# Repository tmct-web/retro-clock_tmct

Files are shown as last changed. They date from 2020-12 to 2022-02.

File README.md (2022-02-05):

# retro-clock_tmct
All discrete logic clock

Retro-clock picture

This is a clock made by combining only logic ICs, so-called DIP components, without using a microcontroller.  
KiCad project files are available.

You can find more information on the following page. (*Japanese only)

[tmct web-site:nixie-clock](https://ss1.xrea.com/tmct.s1009.xrea.com/work/td-ja-7e4l01.html)

---
マイコンを使わず、いわゆるDIP部品のロジックICだけを組み合わせて作った時計です。  
KiCadのプロジェクトファイル一式を公開しています。

設計の仕様・組み立て方などの詳細は下記のページをご覧ください。

[tmct web-site:nixie-clock](https://ss1.xrea.com/tmct.s1009.xrea.com/work/td-ja-7e4l01.html)

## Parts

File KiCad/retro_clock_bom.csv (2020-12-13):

Reference | Quantity | Value | Remarks
C1 | 1 | 1500u/25V | ???????
C11;C12;C14;C13;C8;C17;C18;C2;C16;C9;C15;C10;C19;C20;C21;C22;C28;C24;C26;C29;C27;C25;C23;C34;C35;C41;C40;C42;C39;C38;C44;C43;C60;C61;C62;C55;C49;C63;C46;C64;C54;C48;C47;C52;C59;C65;C58;C57;C71;C72;C77;C82;C78;C83;C79;C84;C80;C85;C81;C86;C73;C74;C75;C76 | 64 | 0.1u/50V | ??????????
C3;C4 | 2 | 10u/400V | ???????
C5;C7;C87;C88;C30;C32;C31;C33;C36;C37;C45;C50;C53;C56;C51;C66;C67;C68;C69;C70 | 20 | 1u/50V | ??????????
C6 | 1 | 100u/16V | ???????
C94;C95;C96;C97;C98;C99;C100 | 7 | 10u/25V | ??????????
CDS1 | 1 | GL5528
CN1 | 1 | B3P-VH(LF)(SN) | JST
CN3 | 1 | XH_B8B-XH-A | JST
CN4;CN2 | 2 | XH_B4B-XH-A | JST
D1 | 1 | S1ZB
D10 | 1 | LED
D4;D5;D7;D8 | 4 | UF2010
D6 | 1 | GDZJ4.7C
D9;D3;D11;D2 | 4 | BAT43
IC1;IC4;IC6 | 3 | 74HC14
IC13;IC27;IC29;IC28;IC45;IC53;IC54;IC55 | 8 | 74HC04
IC15;IC12;IC11;IC38;IC35;IC34 | 6 | 74HC32
IC16 | 1 | 74HC283
IC17;IC14;IC33;IC31;IC30;IC43;IC44;IC46 | 8 | 74HC08
IC2 | 1 | LM2940T-5.0
IC20;IC21;IC22;IC23;IC18;IC19 | 6 | 74HC157
IC25;IC26;IC24;IC39 | 4 | 74HC273
IC3 | 1 | NJU7043
IC32 | 1 | 74HC541
IC36;IC42;IC37;IC56;IC57;IC58 | 6 | 74HC21
IC40;IC41;IC47;IC48;IC49;IC50;IC51;IC52 | 8 | 74HC161
IC5 | 1 | LM393
IC7;IC8;IC9;IC10 | 4 | K155ID1
NE1;NE2;NE3 | 3 | Lamp_Neon | ????
NX1;NX2;NX3;NX4 | 4 | IN-12A | ?????(????????)
PC1 | 1 | TLP222G-2
Q1;Q2 | 2 | MPSA42
R11 | 1 | 2.7k/5%
R13;R12;R7;R15;R35;R38 | 6 | 100k/5%
R14;R3;R22;R21;R20;R23;R24;R5 | 8 | 4.7k/5%
R17;R16;R1;R36;R39 | 5 | 10k/5%
R18;R19 | 2 | 330/5%
R2 | 1 | 8.2k/5%
R25;R26;R27;R28;R10;R9;R29 | 7 | 1k/5%
R30 | 1 | 0
R31;R32;R33;R34;R53;R54;R55;R52 | 8 | 20k/5%/0.5W
R37;R40;R41 | 3 | 200k/5%/0.5W
R4 | 1 | 6.8k/5%
R44;R45;R46;R47;R48;R49;R50;R51;R42;R43 | 10 | 33/5%
R56;R57;R58 | 3 | 33k/5%/0.5W
R6 | 1 | 3.3k/5%
R8 | 1 | 1M/5%/0.5W
RV2;RV1 | 2 | Bourns_3296W/10k | ????????
SW1;SW3;SW4 | 3 | TVDT18-050CB-T | ???????????
SW2;SW5 | 2 | IS-2235-G | ????????????
T1 | 1 | HP-612 | ????????
 |  | HT-1205 | ??????
C89;C90;C93;C91;C92 | 5 | UnPop | ???

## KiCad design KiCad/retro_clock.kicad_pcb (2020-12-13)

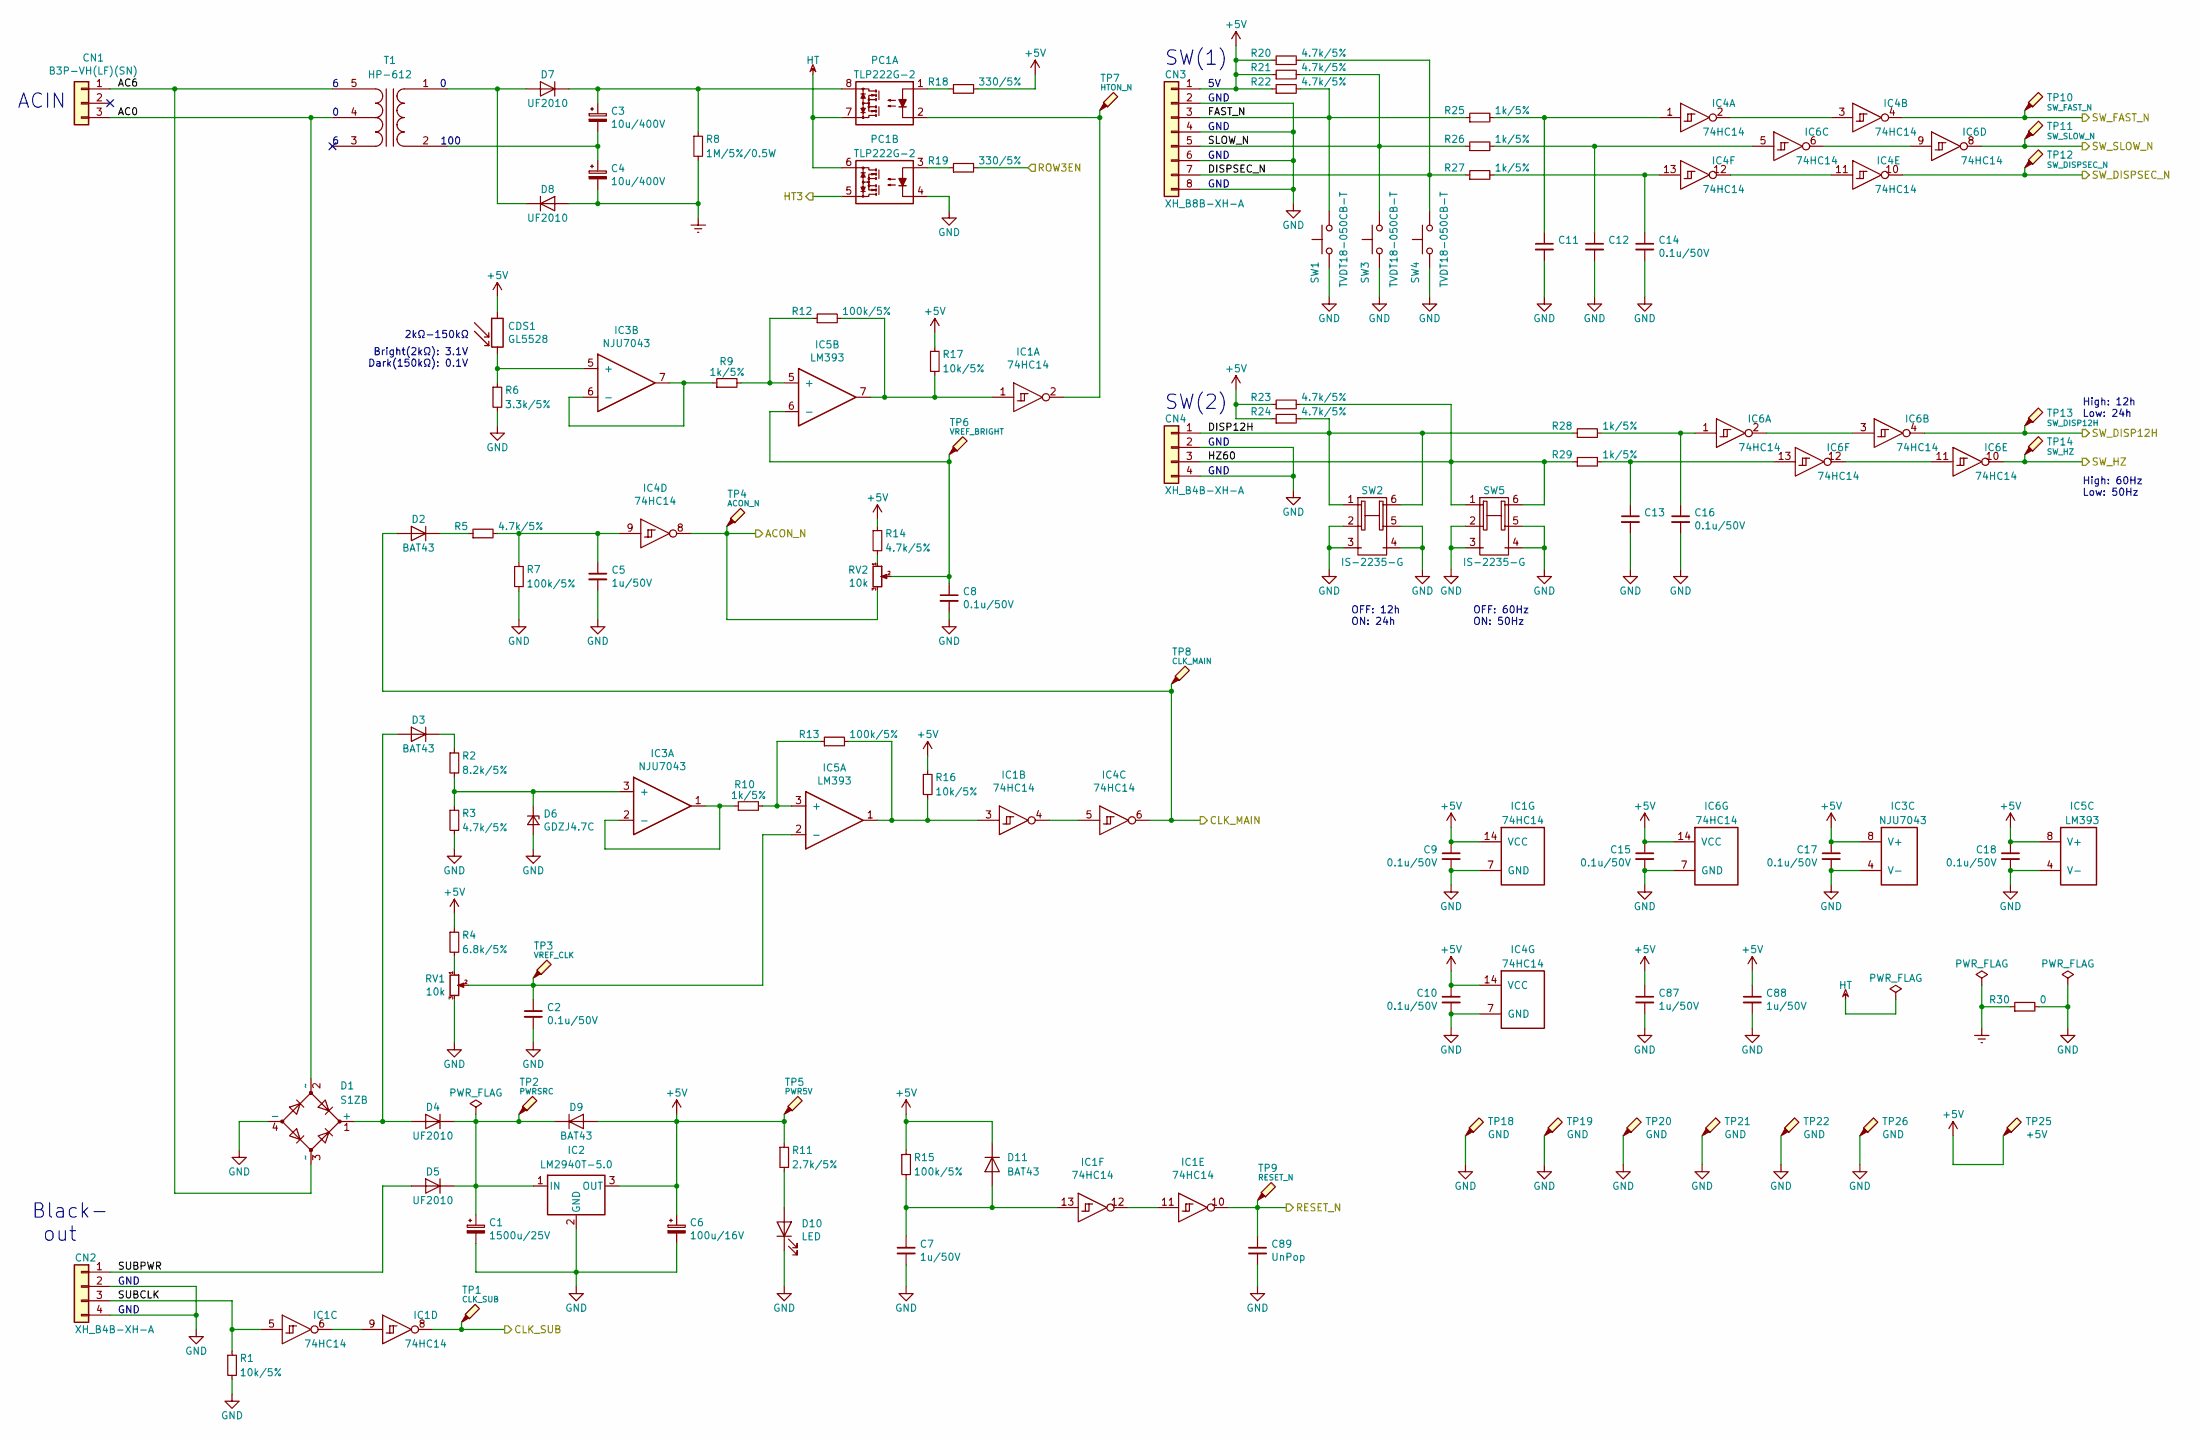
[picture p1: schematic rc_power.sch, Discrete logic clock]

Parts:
C1: 1500u/25V; CP_Radial_D12.5mm_P5.00mm
C2, C8, C9, C10, C11, C12, C13, C14, C15, C16, C17, C18: 0.1u/50V; C_Disc_P2.50mm
C3, C4: 10u/400V; CP_Radial_D12.5mm_P5.00mm
C5, C7, C87, C88: 1u/50V; C_Disc_P2.50mm
C6: 100u/16V; CP_Radial_D5.0mm_P2.00mm
C89: UnPop; C_Disc_P2.50mm
CDS1: GL5528; R_CDS_5.1x4.3mm_P3.4mm_Vertical
CN1: B3P-VH(LF)(SN); JST_VH_B3P-VH-B_1x03_P3.96mm_Vertical
CN2, CN4: XH_B4B-XH-A; JST_XH_B4B-XH-A_1x04_P2.50mm_Vertical
CN3: XH_B8B-XH-A; JST_XH_B8B-XH-A_1x08_P2.50mm_Vertical
D1: S1ZB; S1ZB-THD
D2, D3, D9, D11: BAT43; D_A-405_P7.62mm_Horizontal
D4, D5, D7, D8: UF2010; D_A-405_P10.16mm_Horizontal
D6: GDZJ4.7C; D_A-405_P7.62mm_Horizontal
D10: LED; LED_D3.0mm
IC1, IC4, IC6: 74HC14; DIP-14_W7.62mm_Socket_LongPads
IC2: LM2940T-5.0; TO-220-3_Vertical
IC3: NJU7043; DIP-8_W7.62mm_Socket_LongPads
IC5: LM393; DIP-8_W7.62mm_Socket_LongPads
PC1: TLP222G-2; DIP-8_W7.62mm_Socket_LongPads
R1, R16, R17: 10k/5%; R_Axial_P5.08mm_Horizontal
R2: 8.2k/5%; R_Axial_P5.08mm_Horizontal
R3, R5, R14, R20, R21, R22, R23, R24: 4.7k/5%; R_Axial_P5.08mm_Horizontal
R4: 6.8k/5%; R_Axial_P5.08mm_Horizontal
R6: 3.3k/5%; R_Axial_P5.08mm_Horizontal
R7, R12, R13, R15: 100k/5%; R_Axial_P5.08mm_Horizontal
R8: 1M/5%/0.5W; R_Axial_P7.62mm_Horizontal
R9, R10, R25, R26, R27, R28, R29: 1k/5%; R_Axial_P5.08mm_Horizontal
R11: 2.7k/5%; R_Axial_P5.08mm_Horizontal
R18, R19: 330/5%; R_Axial_P5.08mm_Horizontal
R30: 0; R_Axial_P5.08mm_Horizontal
RV1, RV2: 10k; Potentiometer_Bourns_3296W_Vertical
SW1, SW3, SW4: TVDT18-050CB-T
SW2, SW5: IS-2235-G
T1: HP-612; HP-098
TP1: CLK_SUB; TestPoint_THTPad_1.5x1.5mm_Drill0.7mm
TP2: PWRSRC; TestPoint_THTPad_1.5x1.5mm_Drill0.7mm
TP3: VREF_CLK; TestPoint_THTPad_1.5x1.5mm_Drill0.7mm
TP4: ACON_N; TestPoint_THTPad_1.5x1.5mm_Drill0.7mm
TP5: PWR5V; TestPoint_THTPad_1.5x1.5mm_Drill0.7mm
TP6: VREF_BRIGHT; TestPoint_THTPad_1.5x1.5mm_Drill0.7mm
TP7: HTON_N; TestPoint_THTPad_1.5x1.5mm_Drill0.7mm
TP8: CLK_MAIN; TestPoint_THTPad_1.5x1.5mm_Drill0.7mm
TP9: RESET_N; TestPoint_THTPad_1.5x1.5mm_Drill0.7mm
TP10: SW_FAST_N; TestPoint_THTPad_1.5x1.5mm_Drill0.7mm
TP11: SW_SLOW_N; TestPoint_THTPad_1.5x1.5mm_Drill0.7mm
TP12: SW_DISPSEC_N; TestPoint_THTPad_1.5x1.5mm_Drill0.7mm
TP13: SW_DISP12H; TestPoint_THTPad_1.5x1.5mm_Drill0.7mm
TP14: SW_HZ; TestPoint_THTPad_1.5x1.5mm_Drill0.7mm
TP18, TP19, TP20, TP21, TP22, TP26: GND; TestPoint_Loop_D2.60mm_Drill0.9mm_Beaded
TP25: +5V; TestPoint_Loop_D2.60mm_Drill0.9mm_Beaded

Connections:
+5V: C6.1, C9.1, C10.1, C15.1, C17.1, C18.1, C87.1, C88.1, CDS1.1, CN3.1, D9.2 (A), D11.1 (K), IC1.14 (VCC), IC2.3 (OUT), IC3.8 (V+), IC4.14 (VCC), IC5.8 (V+), IC6.14 (VCC), R4.1, R11.1, R14.1, R15.1, R16.1, R17.1, R18.2, R20.1, R21.1, R22.1, R23.1, R24.1, TP5.1, TP25.1; also elsewhere on the board
/Display block/HT3: PC1.5; also elsewhere on the board
/Divider block/ACON_N: IC4.8, RV2.3, TP4.1; also elsewhere on the board
/Divider block/CLK_MAIN: D2.2 (A), IC4.6, TP8.1; also elsewhere on the board
/Divider block/CLK_SUB: IC1.8, TP1.1; also elsewhere on the board
/Divider block/RESET_N: C89.1, IC1.10, TP9.1; also elsewhere on the board
/Divider block/SW_DISP12H: IC6.4, TP13.1; also elsewhere on the board
/Divider block/SW_DISPSEC_N: IC4.10, TP12.1; also elsewhere on the board
/Divider block/SW_FAST_N: IC4.4, TP10.1; also elsewhere on the board
/Divider block/SW_HZ: IC6.10, TP14.1; also elsewhere on the board
/Divider block/SW_SLOW_N: IC6.8, TP11.1; also elsewhere on the board
/Driver block/ROW3EN: R19.2; also elsewhere on the board
/Power block/AC0: CN1.3, D1.2 (~~), T1.4 (SC)
/Power block/AC6: CN1.1, D1.3 (~~), T1.5 (SB)
/Power block/DISP12H: CN4.1, R24.2, R28.1, SW2.1 (1a), SW2.6 (2a)
/Power block/DISPSEC_N: CN3.7, R20.2, R27.1, SW4.2
/Power block/FAST_N: CN3.3, R22.2, R25.1, SW1.2
/Power block/HZ60: CN4.3, R23.2, R29.1, SW5.1 (1a), SW5.6 (2a)
/Power block/SLOW_N: CN3.5, R21.2, R26.1, SW3.2
/Power block/SUBCLK: CN2.3, IC1.5, R1.1
/Power block/SUBPWR: CN2.1, D5.2 (A)
Earth: C4.2, D8.2 (A), R8.2, R30.1; also elsewhere on the board
GND: C1.2, C2.2, C5.2, C6.2, C7.2, C8.2, C9.2, C10.2, C11.2, C12.2, C13.2, C14.2, C15.2, C16.2, C17.2, C18.2, C87.2, C88.2, C89.2, CN2.2, CN2.4, CN3.2, CN3.4, CN3.6, CN3.8, CN4.2, CN4.4, D1.4 (-), D6.2 (A), D10.1 (K), IC1.7 (GND), IC2.2 (GND), IC3.4 (V-), IC4.7 (GND), IC5.4 (V-), IC6.7 (GND), PC1.4, R1.2, R3.2, R6.2, R7.2, R30.2, RV1.3, SW1.1, SW2.2 (1c), SW2.3 (1b), SW2.4 (2b), SW2.5 (2c), SW3.1, SW4.1, SW5.2 (1c), SW5.3 (1b), SW5.4 (2b), SW5.5 (2c), TP18.1, TP19.1, TP20.1, TP21.1, TP22.1, TP26.1; also elsewhere on the board
HT: PC1.6, PC1.7; also elsewhere on the board
unnamed: C1.1, D4.1 (K), D5.1 (K), D9.1 (K), IC2.1 (IN), TP2.1
unnamed: C2.1, IC5.2 (-), RV1.2, TP3.1
unnamed: C3.1, D7.1 (K), PC1.8, R8.1
unnamed: C3.2, C4.1, T1.2 (AB)
unnamed: C5.1, IC4.9, R5.2, R7.1
unnamed: C7.1, D11.2 (A), IC1.13, R15.2
unnamed: C8.1, IC5.6 (-), RV2.2, TP6.1
unnamed: C11.1, IC4.1, R25.2
unnamed: C12.1, IC6.5, R26.2
unnamed: C13.1, IC6.13, R29.2
unnamed: C14.1, IC4.13, R27.2
unnamed: C16.1, IC6.1, R28.2
unnamed: CDS1.2, IC3.5 (+), R6.1
unnamed: D1.1 (+), D3.2 (A), D4.2 (A)
unnamed: D2.1 (K), R5.1
unnamed: D3.1 (K), R2.1
unnamed: D6.1 (K), IC3.3 (+), R2.2, R3.1
unnamed: D7.2 (A), D8.1 (K), T1.1 (AA)
unnamed: D10.2 (A), R11.2
unnamed: IC1.1, IC5.7, R12.2, R17.2
unnamed: IC1.2, PC1.2, TP7.1
unnamed: IC1.3, IC5.1, R13.2, R16.2
unnamed: IC1.4, IC4.5
unnamed: IC1.6, IC1.9
unnamed: IC1.11, IC1.12
unnamed: IC3.1, IC3.2 (-), R10.1
unnamed: IC3.6 (-), IC3.7, R9.1
unnamed: IC4.2, IC4.3
unnamed: IC4.11, IC4.12
unnamed: IC5.3 (+), R10.2, R13.1
unnamed: IC5.5 (+), R9.2, R12.1
unnamed: IC6.2, IC6.3
unnamed: IC6.6, IC6.9
unnamed: IC6.11, IC6.12
unnamed: PC1.1, R18.1
unnamed: PC1.3, R19.1
unnamed: R4.2, RV1.1
unnamed: R14.2, RV2.1

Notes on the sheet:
ACIN
SW(1)
2kΩ-150kΩ
Bright(2kΩ): 3.1V Dark(150kΩ): 0.1V
SW(2)
Black- out
GND
100
High: 60Hz Low: 50Hz
High: 12h Low: 24h
OFF: 60Hz ON: 50Hz
OFF: 12h ON: 24h

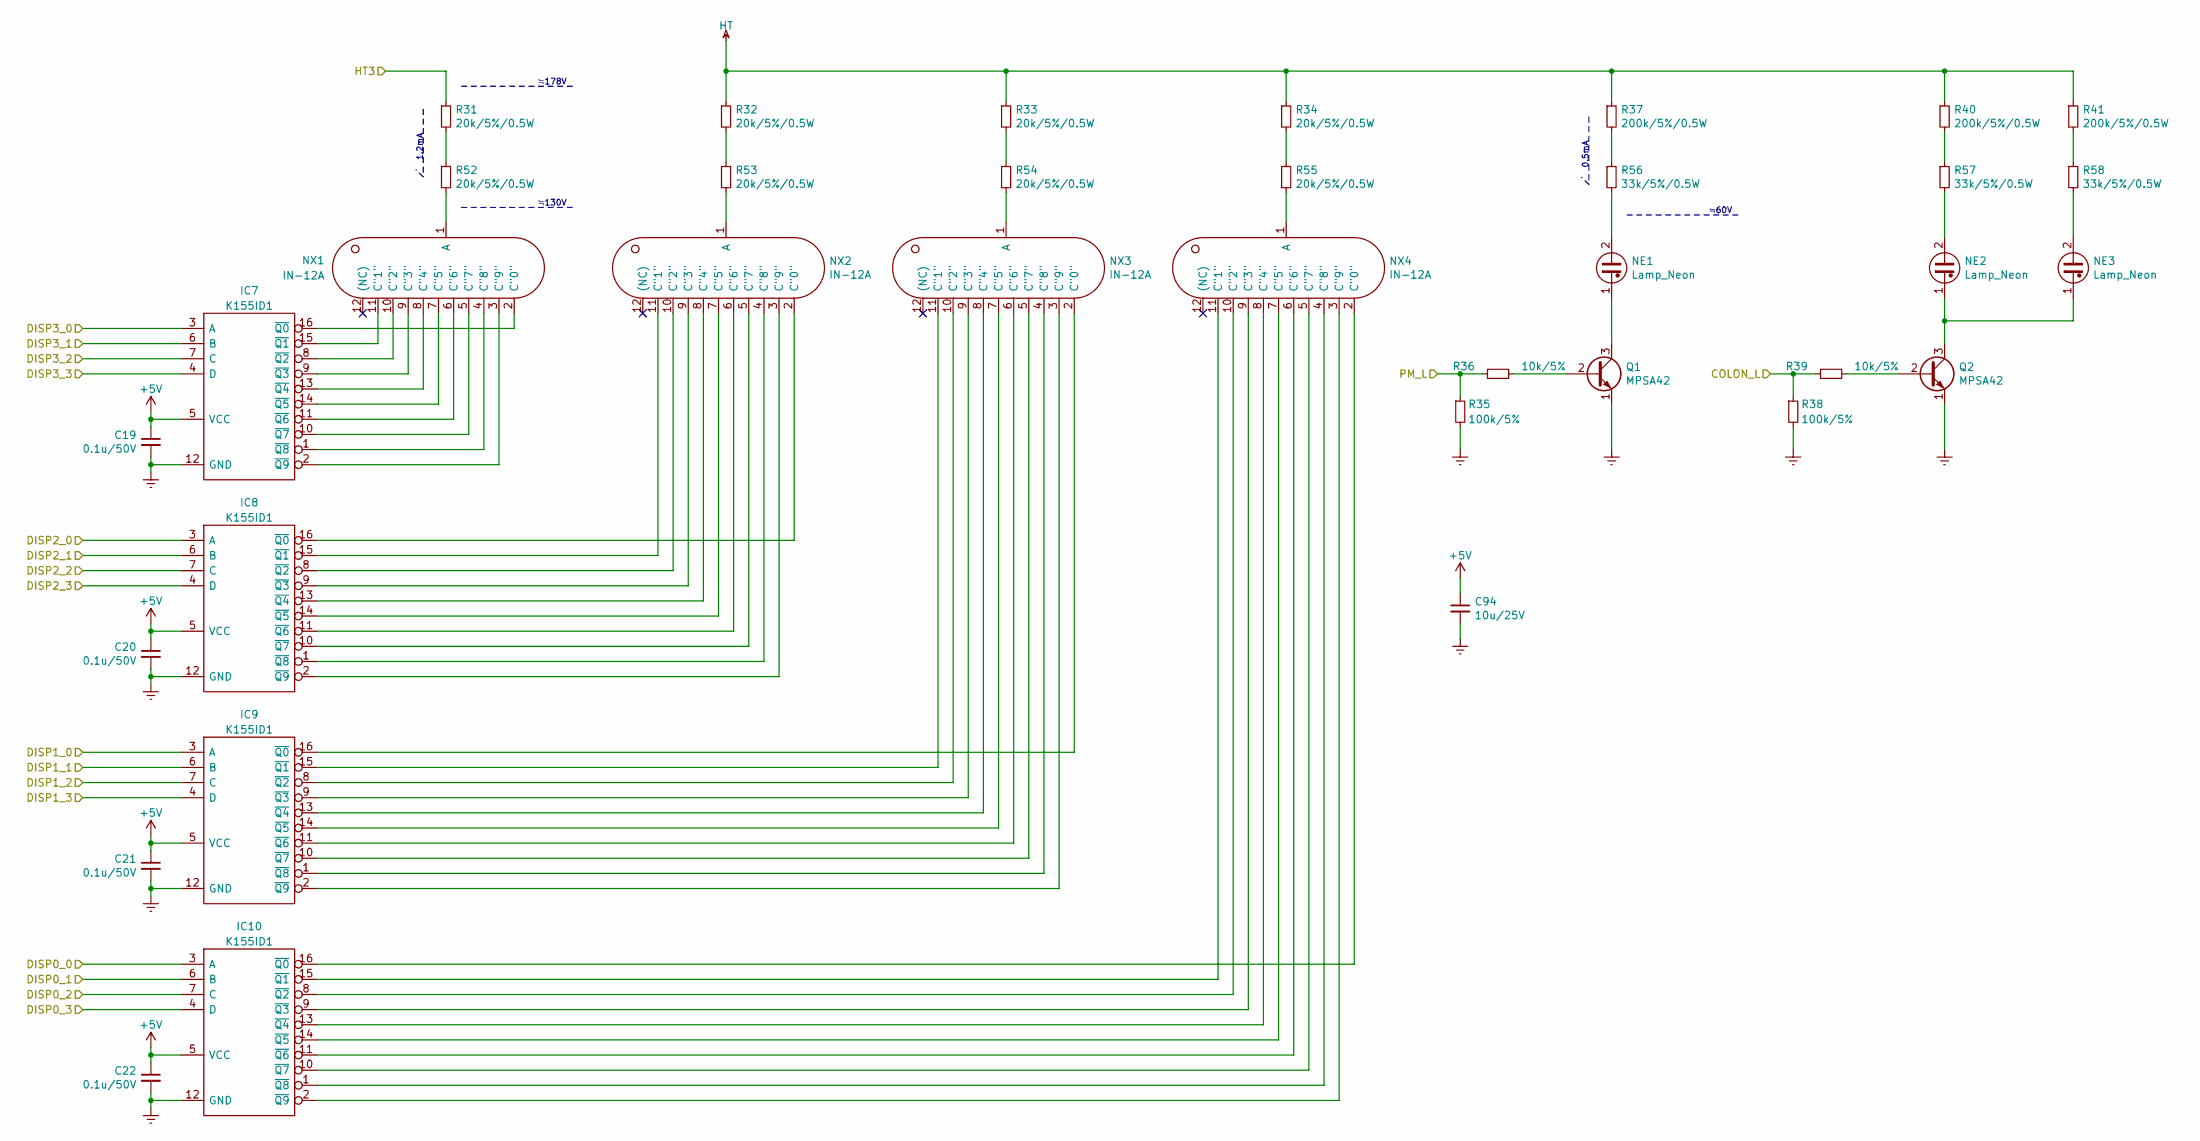
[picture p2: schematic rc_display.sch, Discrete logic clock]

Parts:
C19, C20, C21, C22: 0.1u/50V; C_Disc_P2.50mm
C94: 10u/25V; C_Disc_P5.00mm
IC7, IC8, IC9, IC10: K155ID1; DIP-16_W7.62mm_Socket_LongPads
NE1, NE2, NE3: Lamp_Neon; NeonLamp
NX1, NX2, NX3, NX4: IN-12A; IN-12
Q1, Q2: MPSA42; TO-92_HandSolder
R31, R32, R33, R34, R52, R53, R54, R55: 20k/5%/0.5W; R_Axial_P7.62mm_Horizontal
R35, R38: 100k/5%; R_Axial_P5.08mm_Horizontal
R36, R39: 10k/5%; R_Axial_P5.08mm_Horizontal
R37, R40, R41: 200k/5%/0.5W; R_Axial_P7.62mm_Horizontal
R56, R57, R58: 33k/5%/0.5W; R_Axial_P7.62mm_Horizontal

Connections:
+5V: C19.1, C20.1, C21.1, C22.1, C94.1, IC7.5 (VCC), IC8.5 (VCC), IC9.5 (VCC), IC10.5 (VCC); also elsewhere on the board
/Display block/COLON_L: R38.1, R39.1; also elsewhere on the board
/Display block/DISP0_0: IC10.3 (A); also elsewhere on the board
/Display block/DISP0_1: IC10.6 (B); also elsewhere on the board
/Display block/DISP0_2: IC10.7 (C); also elsewhere on the board
/Display block/DISP0_3: IC10.4 (D); also elsewhere on the board
/Display block/DISP1_0: IC9.3 (A); also elsewhere on the board
/Display block/DISP1_1: IC9.6 (B); also elsewhere on the board
/Display block/DISP1_2: IC9.7 (C); also elsewhere on the board
/Display block/DISP1_3: IC9.4 (D); also elsewhere on the board
/Display block/DISP2_0: IC8.3 (A); also elsewhere on the board
/Display block/DISP2_1: IC8.6 (B); also elsewhere on the board
/Display block/DISP2_2: IC8.7 (C); also elsewhere on the board
/Display block/DISP2_3: IC8.4 (D); also elsewhere on the board
/Display block/DISP3_0: IC7.3 (A); also elsewhere on the board
/Display block/DISP3_1: IC7.6 (B); also elsewhere on the board
/Display block/DISP3_2: IC7.7 (C); also elsewhere on the board
/Display block/DISP3_3: IC7.4 (D); also elsewhere on the board
/Display block/HT3: R31.1; also elsewhere on the board
/Display block/PM_L: R35.1, R36.1; also elsewhere on the board
Earth: C19.2, C20.2, C21.2, C22.2, C94.2, IC7.12 (GND), IC8.12 (GND), IC9.12 (GND), IC10.12 (GND), Q1.1 (E), Q2.1 (E), R35.2, R38.2; also elsewhere on the board
HT: R32.1, R33.1, R34.1, R37.1, R40.1, R41.1; also elsewhere on the board
unnamed: IC7.1 (~Q8), NX1.4 (C"8")
unnamed: IC7.2 (~Q9), NX1.3 (C"9")
unnamed: IC7.8 (~Q2), NX1.10 (C"2")
unnamed: IC7.9 (~Q3), NX1.9 (C"3")
unnamed: IC7.10 (~Q7), NX1.5 (C"7")
unnamed: IC7.11 (~Q6), NX1.6 (C"6")
unnamed: IC7.13 (~Q4), NX1.8 (C"4")
unnamed: IC7.14 (~Q5), NX1.7 (C"5")
unnamed: IC7.15 (~Q1), NX1.11 (C"1")
unnamed: IC7.16 (~Q0), NX1.2 (C"0")
unnamed: IC8.1 (~Q8), NX2.4 (C"8")
unnamed: IC8.2 (~Q9), NX2.3 (C"9")
unnamed: IC8.8 (~Q2), NX2.10 (C"2")
unnamed: IC8.9 (~Q3), NX2.9 (C"3")
unnamed: IC8.10 (~Q7), NX2.5 (C"7")
unnamed: IC8.11 (~Q6), NX2.6 (C"6")
unnamed: IC8.13 (~Q4), NX2.8 (C"4")
unnamed: IC8.14 (~Q5), NX2.7 (C"5")
unnamed: IC8.15 (~Q1), NX2.11 (C"1")
unnamed: IC8.16 (~Q0), NX2.2 (C"0")
unnamed: IC9.1 (~Q8), NX3.4 (C"8")
unnamed: IC9.2 (~Q9), NX3.3 (C"9")
unnamed: IC9.8 (~Q2), NX3.10 (C"2")
unnamed: IC9.9 (~Q3), NX3.9 (C"3")
unnamed: IC9.10 (~Q7), NX3.5 (C"7")
unnamed: IC9.11 (~Q6), NX3.6 (C"6")
unnamed: IC9.13 (~Q4), NX3.8 (C"4")
unnamed: IC9.14 (~Q5), NX3.7 (C"5")
unnamed: IC9.15 (~Q1), NX3.11 (C"1")
unnamed: IC9.16 (~Q0), NX3.2 (C"0")
unnamed: IC10.1 (~Q8), NX4.4 (C"8")
unnamed: IC10.2 (~Q9), NX4.3 (C"9")
unnamed: IC10.8 (~Q2), NX4.10 (C"2")
unnamed: IC10.9 (~Q3), NX4.9 (C"3")
unnamed: IC10.10 (~Q7), NX4.5 (C"7")
unnamed: IC10.11 (~Q6), NX4.6 (C"6")
unnamed: IC10.13 (~Q4), NX4.8 (C"4")
unnamed: IC10.14 (~Q5), NX4.7 (C"5")
unnamed: IC10.15 (~Q1), NX4.11 (C"1")
unnamed: IC10.16 (~Q0), NX4.2 (C"0")
unnamed: NE1.1, Q1.3 (C)
unnamed: NE1.2, R56.2
unnamed: NE2.1, NE3.1, Q2.3 (C)
unnamed: NE2.2, R57.2
unnamed: NE3.2, R58.2
unnamed: NX1.1 (A), R52.2
unnamed: NX2.1 (A), R53.2
unnamed: NX3.1 (A), R54.2
unnamed: NX4.1 (A), R55.2
unnamed: Q1.2 (B), R36.2
unnamed: Q2.2 (B), R39.2
unnamed: R31.2, R52.1
unnamed: R32.2, R53.1
unnamed: R33.2, R54.1
unnamed: R34.2, R55.1
unnamed: R37.2, R56.1
unnamed: R40.2, R57.1
unnamed: R41.2, R58.1

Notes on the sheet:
1.2mA
≒178V
≒130V
0.5mA
≒60V

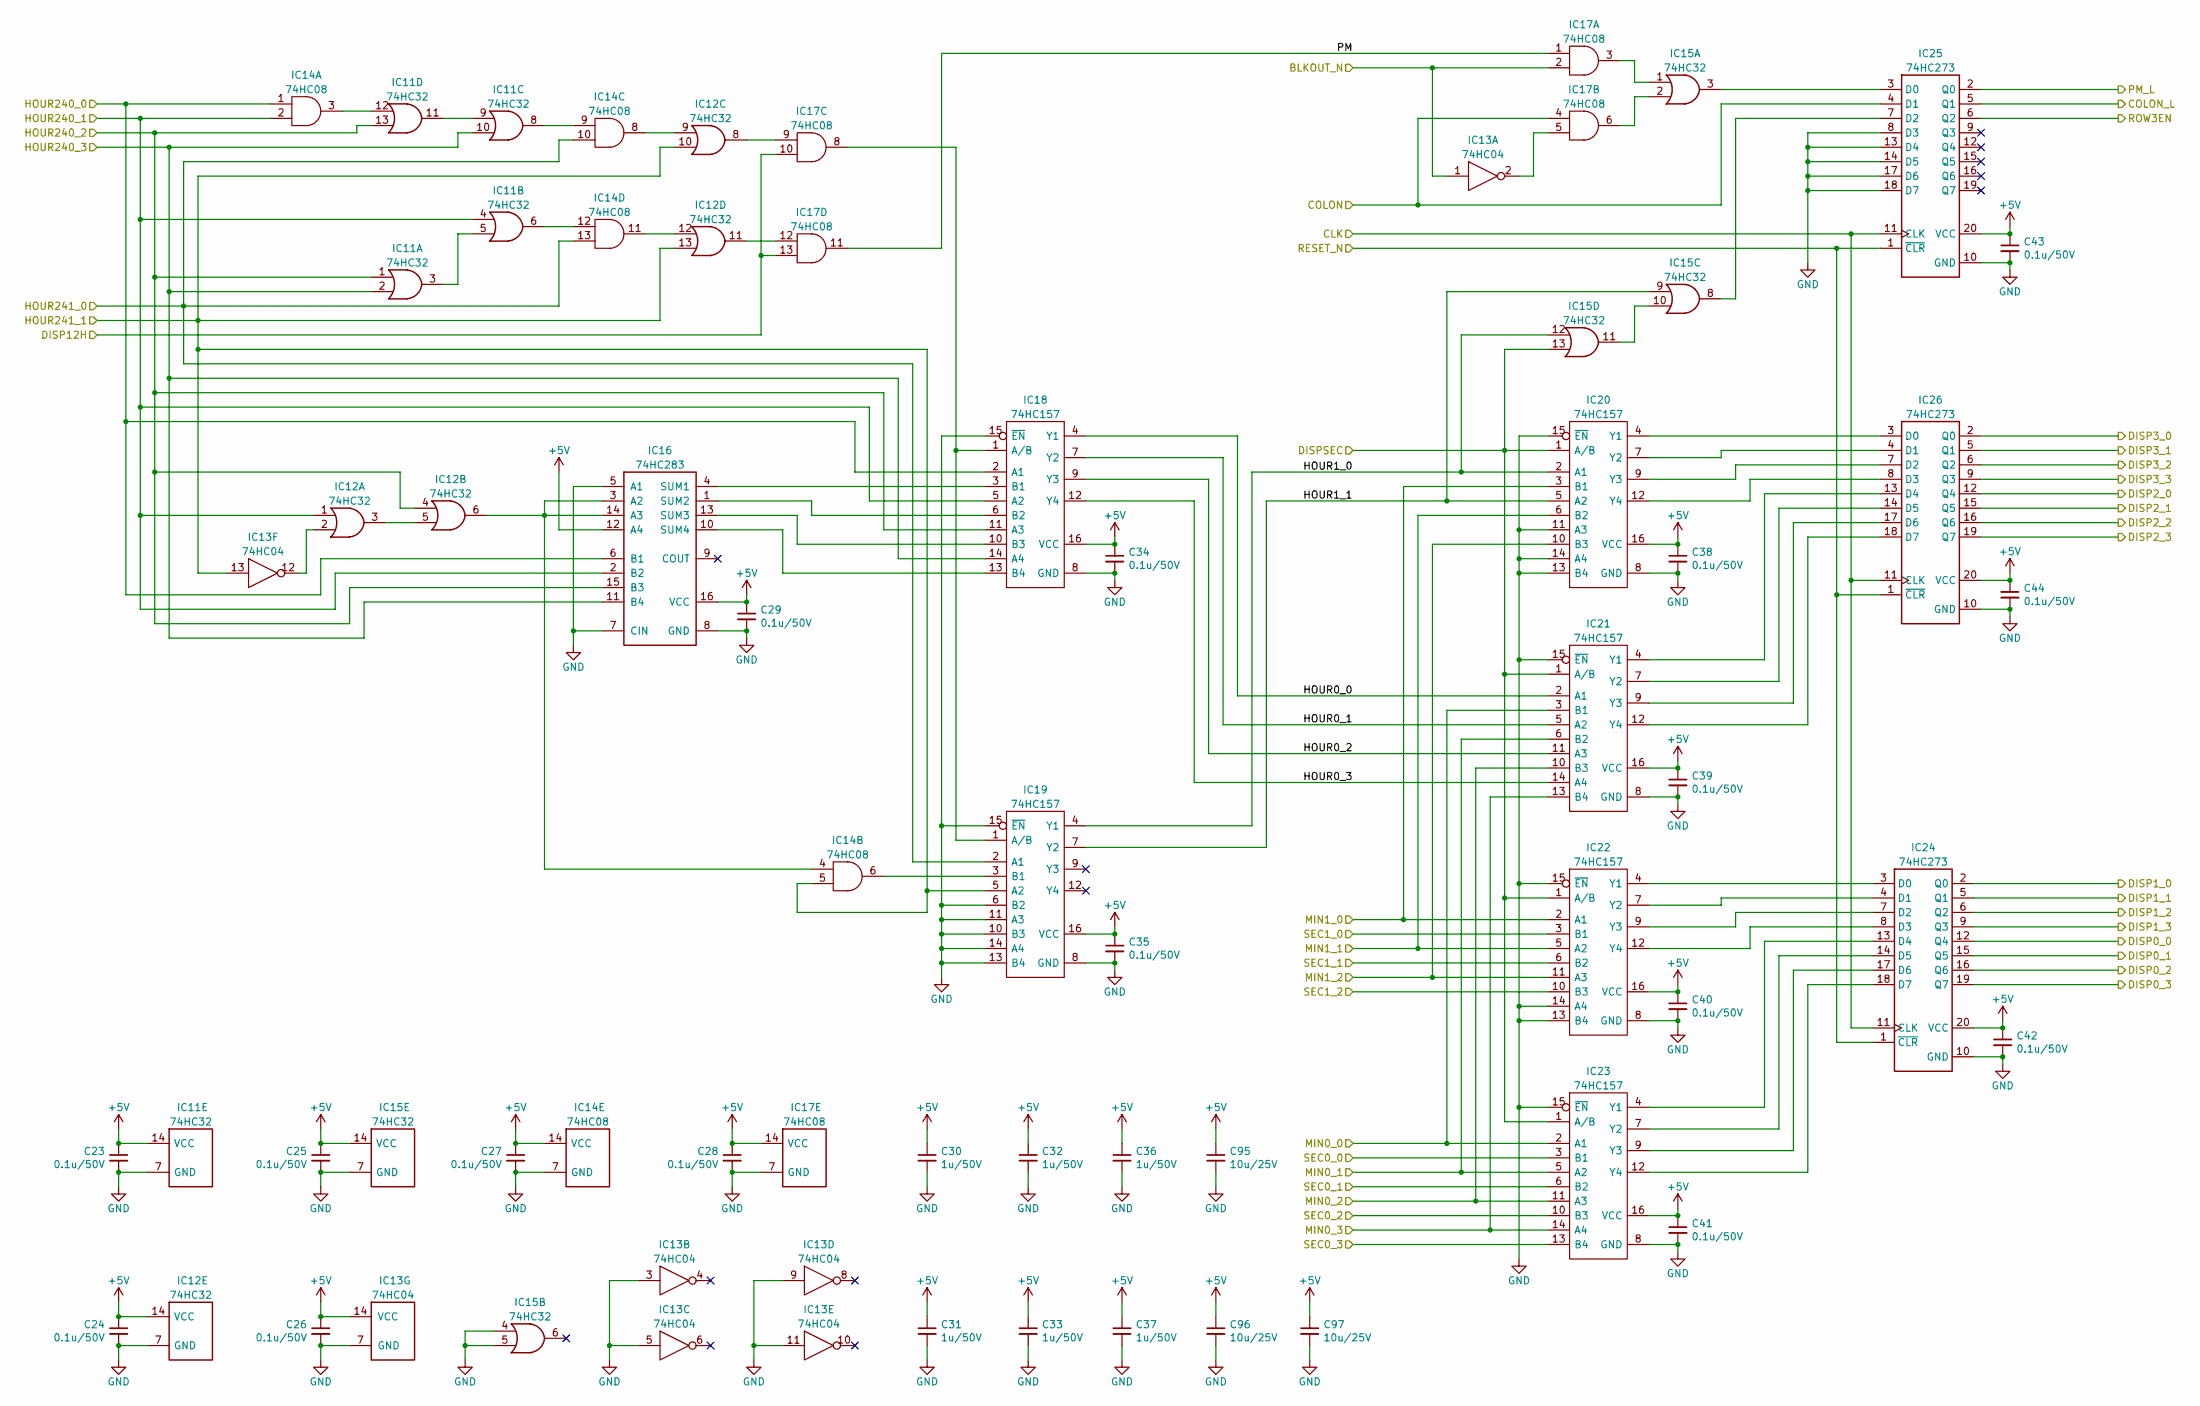
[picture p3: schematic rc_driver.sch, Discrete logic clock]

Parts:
C23, C24, C25, C26, C27, C28, C29, C34, C35, C38, C39, C40, C41, C42, C43, C44: 0.1u/50V; C_Disc_P2.50mm
C30, C31, C32, C33, C36, C37: 1u/50V; C_Disc_P2.50mm
C95, C96, C97: 10u/25V; C_Disc_P5.00mm
IC11, IC12, IC15: 74HC32; DIP-14_W7.62mm_Socket_LongPads
IC13: 74HC04; DIP-14_W7.62mm_Socket_LongPads
IC14, IC17: 74HC08; DIP-14_W7.62mm_Socket_LongPads
IC16: 74HC283; DIP-16_W7.62mm_Socket_LongPads
IC18, IC19, IC20, IC21, IC22, IC23: 74HC157; DIP-16_W7.62mm_Socket_LongPads
IC24, IC25, IC26: 74HC273; DIP-20_W7.62mm_Socket_LongPads

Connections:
+5V: C23.1, C24.1, C25.1, C26.1, C27.1, C28.1, C29.1, C30.1, C31.1, C32.1, C33.1, C34.1, C35.1, C36.1, C37.1, C38.1, C39.1, C40.1, C41.1, C42.1, C43.1, C44.1, C95.1, C96.1, C97.1, IC11.14 (VCC), IC12.14 (VCC), IC13.14 (VCC), IC14.14 (VCC), IC15.14 (VCC), IC16.12 (A4), IC16.16 (VCC), IC17.14 (VCC), IC18.16 (VCC), IC19.16 (VCC), IC20.16 (VCC), IC21.16 (VCC), IC22.16 (VCC), IC23.16 (VCC), IC24.20 (VCC), IC25.20 (VCC), IC26.20 (VCC); also elsewhere on the board
/Display block/COLON_L: IC25.5 (Q1); also elsewhere on the board
/Display block/DISP0_0: IC24.12 (Q4); also elsewhere on the board
/Display block/DISP0_1: IC24.15 (Q5); also elsewhere on the board
/Display block/DISP0_2: IC24.16 (Q6); also elsewhere on the board
/Display block/DISP0_3: IC24.19 (Q7); also elsewhere on the board
/Display block/DISP1_0: IC24.2 (Q0); also elsewhere on the board
/Display block/DISP1_1: IC24.5 (Q1); also elsewhere on the board
/Display block/DISP1_2: IC24.6 (Q2); also elsewhere on the board
/Display block/DISP1_3: IC24.9 (Q3); also elsewhere on the board
/Display block/DISP2_0: IC26.12 (Q4); also elsewhere on the board
/Display block/DISP2_1: IC26.15 (Q5); also elsewhere on the board
/Display block/DISP2_2: IC26.16 (Q6); also elsewhere on the board
/Display block/DISP2_3: IC26.19 (Q7); also elsewhere on the board
/Display block/DISP3_0: IC26.2 (Q0); also elsewhere on the board
/Display block/DISP3_1: IC26.5 (Q1); also elsewhere on the board
/Display block/DISP3_2: IC26.6 (Q2); also elsewhere on the board
/Display block/DISP3_3: IC26.9 (Q3); also elsewhere on the board
/Display block/PM_L: IC25.2 (Q0); also elsewhere on the board
/Divider block/BLKOUT_N: IC13.1, IC17.2; also elsewhere on the board
/Divider block/COLON: IC17.4, IC25.4 (D1); also elsewhere on the board
/Divider block/DISP12H: IC17.10, IC17.13; also elsewhere on the board
/Divider block/DISPSEC: IC15.13, IC20.1 (A/B), IC21.1 (A/B), IC22.1 (A/B), IC23.1 (A/B); also elsewhere on the board
/Divider block/RESET_DRV_N: IC24.1 (~CLR), IC25.1 (~CLR), IC26.1 (~CLR); also elsewhere on the board
/Driver block/CLK: IC24.11 (CLK), IC25.11 (CLK), IC26.11 (CLK); also elsewhere on the board
/Driver block/HOUR0_0: IC18.4 (Y1), IC21.2 (A1)
/Driver block/HOUR0_1: IC18.7 (Y2), IC21.5 (A2)
/Driver block/HOUR0_2: IC18.9 (Y3), IC21.11 (A3)
/Driver block/HOUR0_3: IC18.12 (Y4), IC21.14 (A4)
/Driver block/HOUR1_0: IC15.12, IC19.4 (Y1), IC20.2 (A1)
/Driver block/HOUR1_1: IC15.9, IC19.7 (Y2), IC20.5 (A2)
/Driver block/HOUR240_0: IC14.1, IC16.6 (B1), IC18.2 (A1); also elsewhere on the board
/Driver block/HOUR240_1: IC11.4, IC12.1, IC14.2, IC16.2 (B2), IC18.5 (A2); also elsewhere on the board
/Driver block/HOUR240_2: IC11.1, IC11.13, IC12.4, IC16.15 (B3), IC18.11 (A3); also elsewhere on the board
/Driver block/HOUR240_3: IC11.2, IC11.10, IC16.11 (B4), IC18.14 (A4); also elsewhere on the board
/Driver block/HOUR241_0: IC14.10, IC14.13, IC19.2 (A1); also elsewhere on the board
/Driver block/HOUR241_1: IC12.10, IC12.13, IC13.13, IC14.5, IC19.5 (A2); also elsewhere on the board
/Driver block/MIN0_0: IC21.3 (B1), IC23.2 (A1); also elsewhere on the board
/Driver block/MIN0_1: IC21.6 (B2), IC23.5 (A2); also elsewhere on the board
/Driver block/MIN0_2: IC21.10 (B3), IC23.11 (A3); also elsewhere on the board
/Driver block/MIN0_3: IC21.13 (B4), IC23.14 (A4); also elsewhere on the board
/Driver block/MIN1_0: IC20.3 (B1), IC22.2 (A1); also elsewhere on the board
/Driver block/MIN1_1: IC20.6 (B2), IC22.5 (A2); also elsewhere on the board
/Driver block/MIN1_2: IC20.10 (B3), IC22.11 (A3); also elsewhere on the board
/Driver block/PM: IC17.1, IC17.11
/Driver block/ROW3EN: IC25.6 (Q2); also elsewhere on the board
/Driver block/SEC0_0: IC23.3 (B1); also elsewhere on the board
/Driver block/SEC0_1: IC23.6 (B2); also elsewhere on the board
/Driver block/SEC0_2: IC23.10 (B3); also elsewhere on the board
/Driver block/SEC0_3: IC23.13 (B4); also elsewhere on the board
/Driver block/SEC1_0: IC22.3 (B1); also elsewhere on the board
/Driver block/SEC1_1: IC22.6 (B2); also elsewhere on the board
/Driver block/SEC1_2: IC22.10 (B3); also elsewhere on the board
GND: C23.2, C24.2, C25.2, C26.2, C27.2, C28.2, C29.2, C30.2, C31.2, C32.2, C33.2, C34.2, C35.2, C36.2, C37.2, C38.2, C39.2, C40.2, C41.2, C42.2, C43.2, C44.2, C95.2, C96.2, C97.2, IC11.7 (GND), IC12.7 (GND), IC13.3, IC13.5, IC13.7 (GND), IC13.9, IC13.11, IC14.7 (GND), IC15.4, IC15.5, IC15.7 (GND), IC16.5 (A1), IC16.7 (CIN), IC16.8 (GND), IC17.7 (GND), IC18.8 (GND), IC18.15 (~EN), IC19.6 (B2), IC19.8 (GND), IC19.10 (B3), IC19.11 (A3), IC19.13 (B4), IC19.14 (A4), IC19.15 (~EN), IC20.8 (GND), IC20.11 (A3), IC20.13 (B4), IC20.14 (A4), IC20.15 (~EN), IC21.8 (GND), IC21.15 (~EN), IC22.8 (GND), IC22.13 (B4), IC22.14 (A4), IC22.15 (~EN), IC23.8 (GND), IC23.15 (~EN), IC24.10 (GND), IC25.8 (D3), IC25.10 (GND), IC25.13 (D4), IC25.14 (D5), IC25.17 (D6), IC25.18 (D7), IC26.10 (GND); also elsewhere on the board
unnamed: IC11.3, IC11.5
unnamed: IC11.6, IC14.12
unnamed: IC11.8, IC14.9
unnamed: IC11.9, IC11.11
unnamed: IC11.12, IC14.3
unnamed: IC12.2, IC13.12
unnamed: IC12.3, IC12.5
unnamed: IC12.6, IC14.4, IC16.3 (A2), IC16.14 (A3)
unnamed: IC12.8, IC17.9
unnamed: IC12.9, IC14.8
unnamed: IC12.11, IC17.12
unnamed: IC12.12, IC14.11
unnamed: IC13.2, IC17.5
unnamed: IC14.6, IC19.3 (B1)
unnamed: IC15.1, IC17.3
unnamed: IC15.2, IC17.6
unnamed: IC15.3, IC25.3 (D0)
unnamed: IC15.8, IC25.7 (D2)
unnamed: IC15.10, IC15.11
unnamed: IC16.1 (SUM2), IC18.6 (B2)
unnamed: IC16.4 (SUM1), IC18.3 (B1)
unnamed: IC16.10 (SUM4), IC18.13 (B4)
unnamed: IC16.13 (SUM3), IC18.10 (B3)
unnamed: IC17.8, IC18.1 (A/B), IC19.1 (A/B)
unnamed: IC20.4 (Y1), IC26.3 (D0)
unnamed: IC20.7 (Y2), IC26.4 (D1)
unnamed: IC20.9 (Y3), IC26.7 (D2)
unnamed: IC20.12 (Y4), IC26.8 (D3)
unnamed: IC21.4 (Y1), IC26.13 (D4)
unnamed: IC21.7 (Y2), IC26.14 (D5)
unnamed: IC21.9 (Y3), IC26.17 (D6)
unnamed: IC21.12 (Y4), IC26.18 (D7)
unnamed: IC22.4 (Y1), IC24.3 (D0)
unnamed: IC22.7 (Y2), IC24.4 (D1)
unnamed: IC22.9 (Y3), IC24.7 (D2)
unnamed: IC22.12 (Y4), IC24.8 (D3)
unnamed: IC23.4 (Y1), IC24.13 (D4)
unnamed: IC23.7 (Y2), IC24.14 (D5)
unnamed: IC23.9 (Y3), IC24.17 (D6)
unnamed: IC23.12 (Y4), IC24.18 (D7)

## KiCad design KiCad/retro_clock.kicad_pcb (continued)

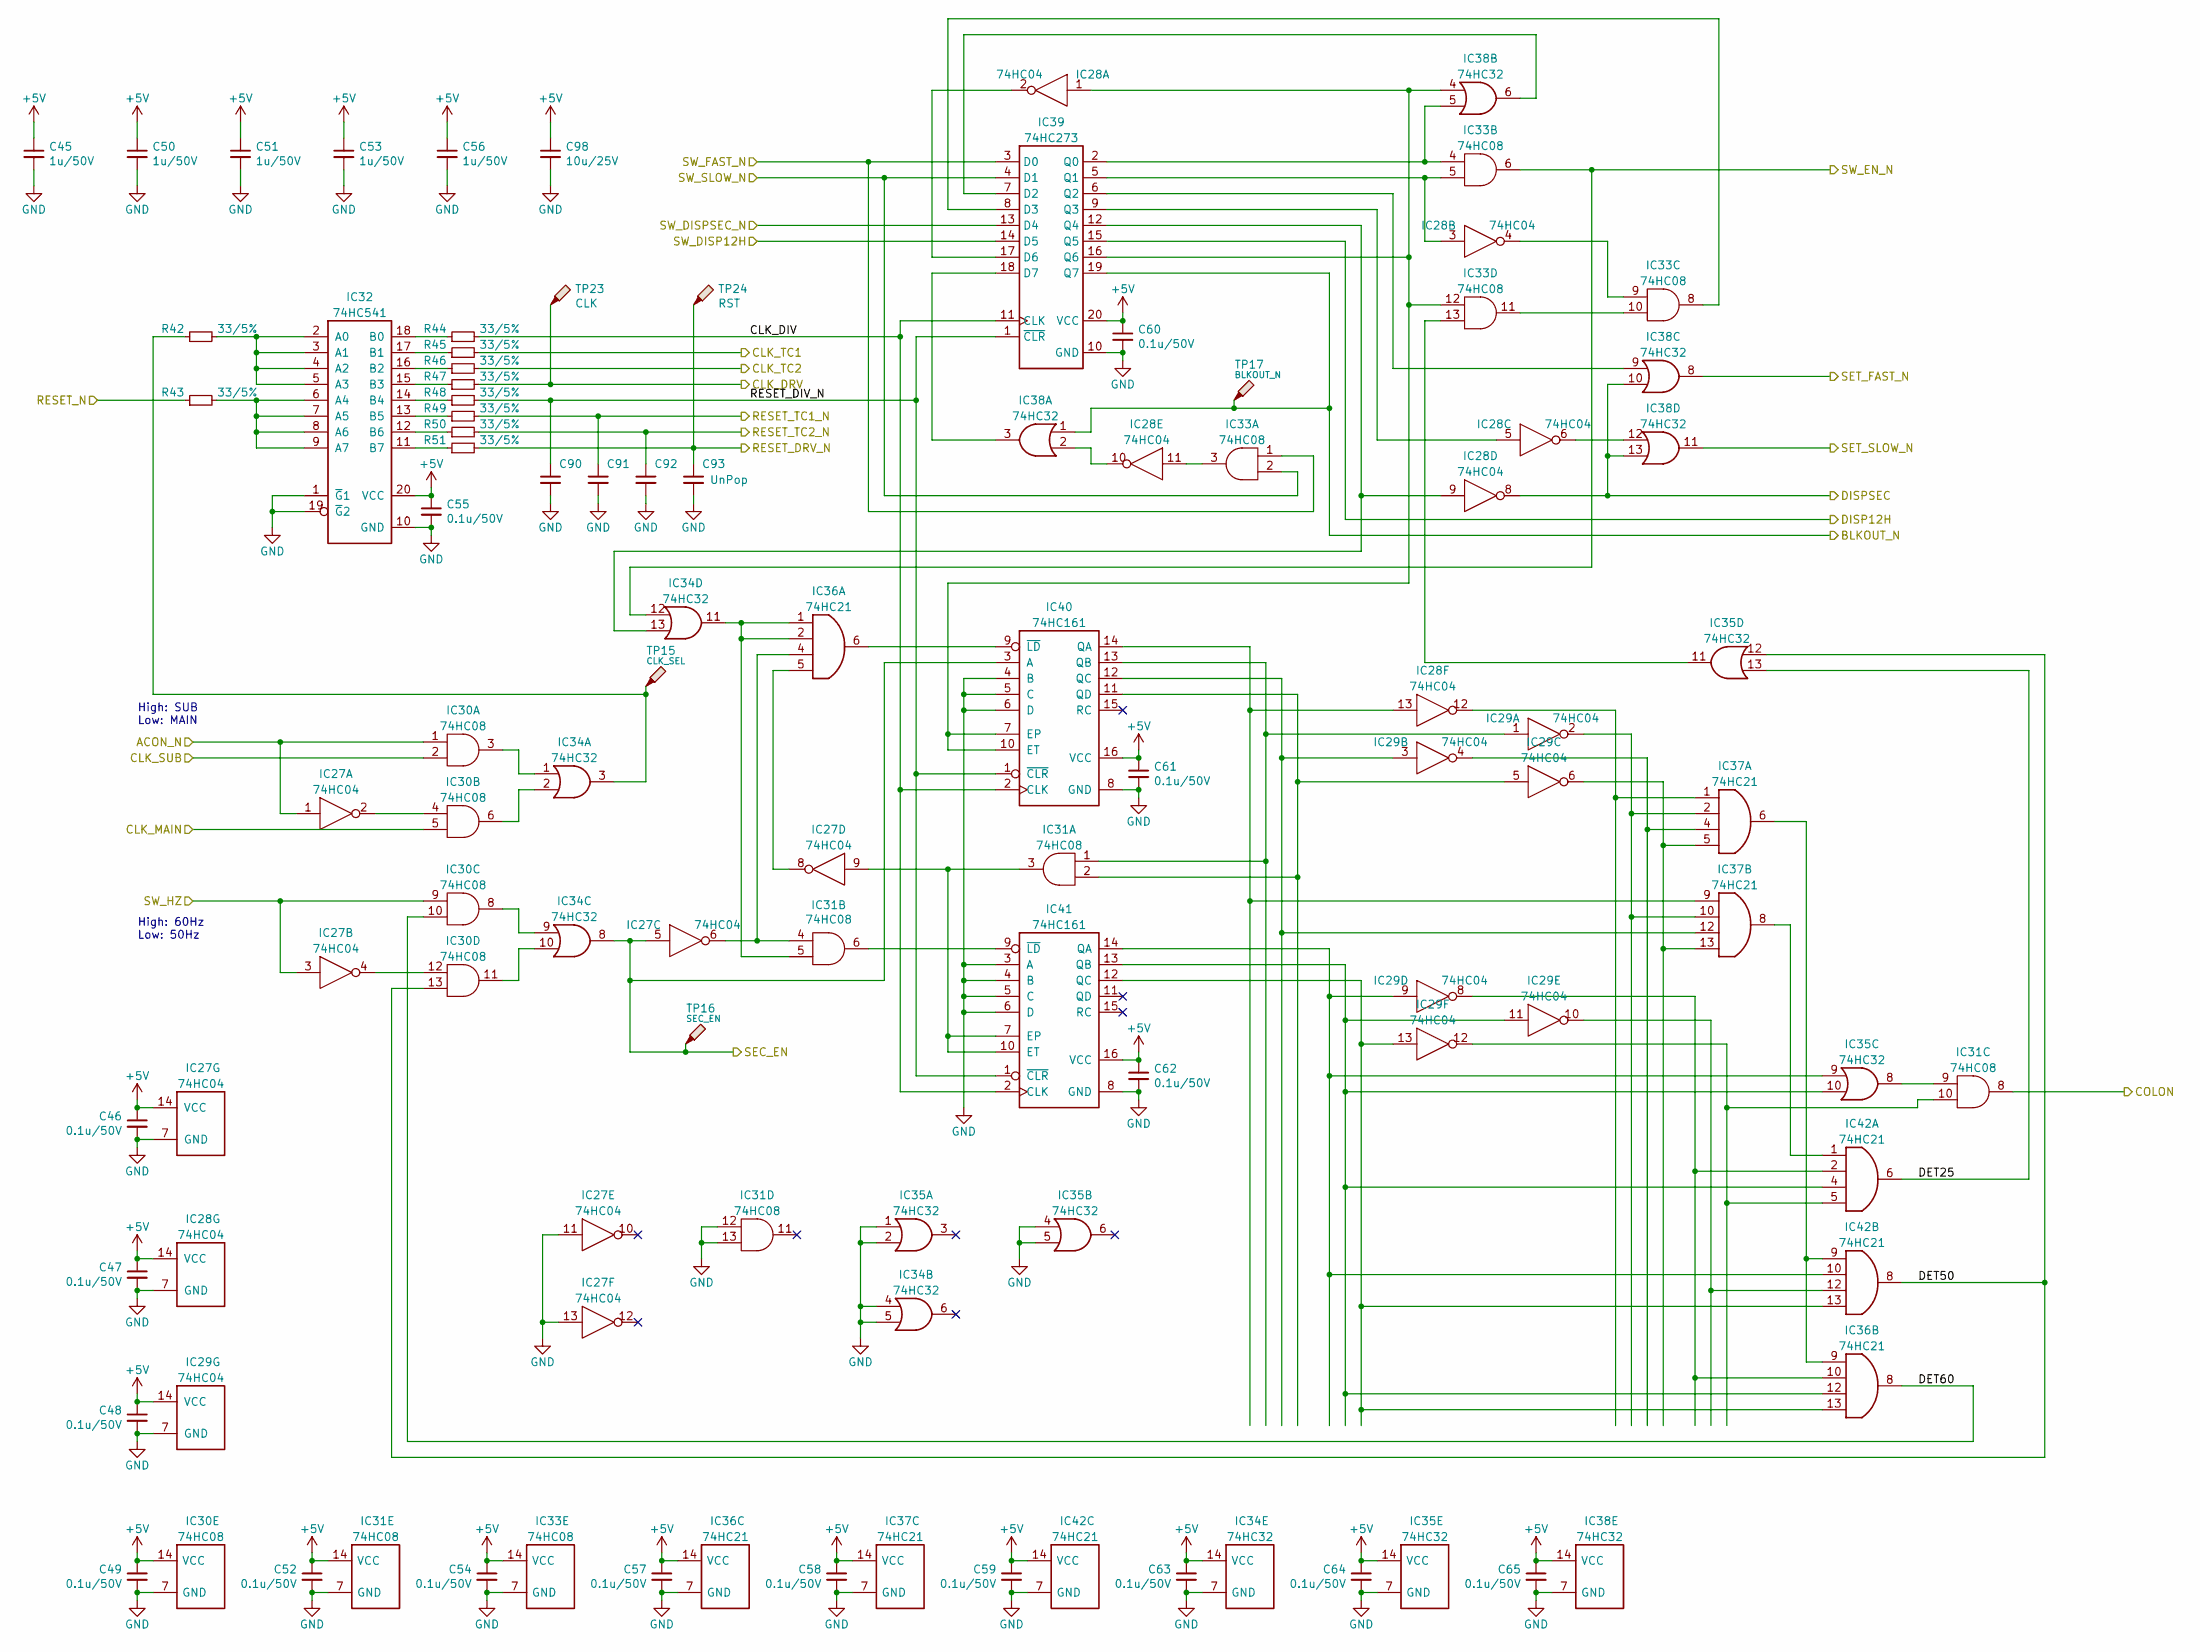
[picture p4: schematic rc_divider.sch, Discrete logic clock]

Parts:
C45, C50, C51, C53, C56: 1u/50V; C_Disc_P2.50mm
C46, C47, C48, C49, C52, C54, C55, C57, C58, C59, C60, C61, C62, C63, C64, C65: 0.1u/50V; C_Disc_P2.50mm
C90, C91, C92, C93: UnPop; C_Disc_P2.50mm
C98: 10u/25V; C_Disc_P5.00mm
IC27, IC28, IC29: 74HC04; DIP-14_W7.62mm_Socket_LongPads
IC30, IC31, IC33: 74HC08; DIP-14_W7.62mm_Socket_LongPads
IC32: 74HC541; DIP-20_W7.62mm_Socket_LongPads
IC34, IC35, IC38: 74HC32; DIP-14_W7.62mm_Socket_LongPads
IC36, IC37, IC42: 74HC21; DIP-14_W7.62mm_Socket_LongPads
IC39: 74HC273; DIP-20_W7.62mm_Socket_LongPads
IC40, IC41: 74HC161; DIP-16_W7.62mm_Socket_LongPads
R42, R43, R44, R45, R46, R47, R48, R49, R50, R51: 33/5%; R_Axial_P5.08mm_Horizontal
TP15: CLK_SEL; TestPoint_THTPad_1.5x1.5mm_Drill0.7mm
TP16: SEC_EN; TestPoint_THTPad_1.5x1.5mm_Drill0.7mm
TP17: BLKOUT_N; TestPoint_THTPad_1.5x1.5mm_Drill0.7mm
TP23: CLK; TestPoint_Loop_D2.60mm_Drill0.9mm_Beaded
TP24: RST; TestPoint_Loop_D2.60mm_Drill0.9mm_Beaded

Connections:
+5V: C45.1, C46.1, C47.1, C48.1, C49.1, C50.1, C51.1, C52.1, C53.1, C54.1, C55.1, C56.1, C57.1, C58.1, C59.1, C60.1, C61.1, C62.1, C63.1, C64.1, C65.1, C98.1, IC27.14 (VCC), IC28.14 (VCC), IC29.14 (VCC), IC30.14 (VCC), IC31.14 (VCC), IC32.20 (VCC), IC33.14 (VCC), IC34.14 (VCC), IC35.14 (VCC), IC36.14 (VCC), IC37.14 (VCC), IC38.14 (VCC), IC39.20 (VCC), IC40.16 (VCC), IC41.16 (VCC), IC42.14 (VCC); also elsewhere on the board
/Divider block/ACON_N: IC27.1, IC30.1; also elsewhere on the board
/Divider block/BLKOUT_N: IC38.1, IC39.19 (Q7), TP17.1; also elsewhere on the board
/Divider block/CLK_DIV: IC39.11 (CLK), IC40.2 (CLK), IC41.2 (CLK), R44.2
/Divider block/CLK_MAIN: IC30.5; also elsewhere on the board
/Divider block/CLK_SUB: IC30.2; also elsewhere on the board
/Divider block/COLON: IC31.8; also elsewhere on the board
/Divider block/DET25: IC35.13, IC42.6
/Divider block/DET50: IC30.13, IC35.12, IC42.8
/Divider block/DET60: IC30.10, IC36.8
/Divider block/DISP12H: IC39.15 (Q5); also elsewhere on the board
/Divider block/DISPSEC: IC28.8, IC38.10, IC38.13; also elsewhere on the board
/Divider block/RESET_DIV_N: C90.1, IC39.1 (~CLR), IC40.1 (~CLR), IC41.1 (~CLR), R48.2
/Divider block/RESET_DRV_N: C93.1, R51.2, TP24.1; also elsewhere on the board
/Divider block/RESET_N: R43.1; also elsewhere on the board
/Divider block/SEC_EN: IC27.5, IC34.8, IC40.3 (A), TP16.1; also elsewhere on the board
/Divider block/SET_FAST_N: IC38.8; also elsewhere on the board
/Divider block/SET_SLOW_N: IC38.11; also elsewhere on the board
/Divider block/SW_DISP12H: IC39.14 (D5); also elsewhere on the board
/Divider block/SW_DISPSEC_N: IC39.13 (D4); also elsewhere on the board
/Divider block/SW_FAST_N: IC33.1, IC39.3 (D0); also elsewhere on the board
/Divider block/SW_HZ: IC27.3, IC30.9; also elsewhere on the board
/Divider block/SW_SLOW_N: IC33.2, IC39.4 (D1); also elsewhere on the board
/Driver block/CLK: R47.2, TP23.1; also elsewhere on the board
/Time count block/CLK1: R45.2; also elsewhere on the board
/Time count block/CLK2: R46.2; also elsewhere on the board
/Time count block/RESET1_N: C91.1, R49.2; also elsewhere on the board
/Time count block/RESET2_N: C92.1, R50.2; also elsewhere on the board
/Time count block/SET_EN_N: IC33.6, IC34.12; also elsewhere on the board
GND: C45.2, C46.2, C47.2, C48.2, C49.2, C50.2, C51.2, C52.2, C53.2, C54.2, C55.2, C56.2, C57.2, C58.2, C59.2, C60.2, C61.2, C62.2, C63.2, C64.2, C65.2, C90.2, C91.2, C92.2, C93.2, C98.2, IC27.7 (GND), IC27.11, IC27.13, IC28.7 (GND), IC29.7 (GND), IC30.7 (GND), IC31.7 (GND), IC31.12, IC31.13, IC32.1 (~G~1), IC32.10 (GND), IC32.19 (~G~2), IC33.7 (GND), IC34.4, IC34.5, IC34.7 (GND), IC35.1, IC35.2, IC35.4, IC35.5, IC35.7 (GND), IC36.7 (GND), IC37.7 (GND), IC38.7 (GND), IC39.10 (GND), IC40.4 (B), IC40.5 (C), IC40.6 (D), IC40.8 (GND), IC41.3 (A), IC41.4 (B), IC41.5 (C), IC41.6 (D), IC41.8 (GND), IC42.7 (GND); also elsewhere on the board
unnamed: IC27.2, IC30.4
unnamed: IC27.4, IC30.12
unnamed: IC27.6, IC31.4, IC36.4
unnamed: IC27.8, IC36.5
unnamed: IC27.9, IC31.3, IC41.7 (EP), IC41.10 (ET)
unnamed: IC28.1, IC33.12, IC38.4, IC39.16 (Q6), IC40.7 (EP), IC40.10 (ET)
unnamed: IC28.2, IC39.17 (D6)
unnamed: IC28.3, IC33.5, IC39.5 (Q1)
unnamed: IC28.4, IC33.9
unnamed: IC28.5, IC39.9 (Q3)
unnamed: IC28.6, IC38.12
unnamed: IC28.9, IC34.13, IC39.12 (Q4)
unnamed: IC28.10, IC38.2
unnamed: IC28.11, IC33.3
unnamed: IC28.12, IC37.1
unnamed: IC28.13, IC37.9, IC40.14 (QA)
unnamed: IC29.1, IC31.1, IC40.13 (QB)
unnamed: IC29.2, IC37.2, IC37.10
unnamed: IC29.3, IC37.12, IC40.12 (QC)
unnamed: IC29.4, IC37.4
unnamed: IC29.5, IC31.2, IC40.11 (QD)
unnamed: IC29.6, IC37.5, IC37.13
unnamed: IC29.8, IC36.10, IC42.2
unnamed: IC29.9, IC35.9, IC41.14 (QA), IC42.10
unnamed: IC29.10, IC42.12
unnamed: IC29.11, IC35.10, IC36.12, IC41.13 (QB), IC42.4
unnamed: IC29.12, IC31.10, IC42.5
unnamed: IC29.13, IC36.13, IC41.12 (QC), IC42.13
unnamed: IC30.3, IC34.1
unnamed: IC30.6, IC34.2
unnamed: IC30.8, IC34.9
unnamed: IC30.11, IC34.10
unnamed: IC31.5, IC34.11, IC36.1, IC36.2
unnamed: IC31.6, IC41.9 (~LD)
unnamed: IC31.9, IC35.8
unnamed: IC32.2 (A0), IC32.3 (A1), IC32.4 (A2), IC32.5 (A3), R42.2
unnamed: IC32.6 (A4), IC32.7 (A5), IC32.8 (A6), IC32.9 (A7), R43.2
unnamed: IC32.11 (B7), R51.1
unnamed: IC32.12 (B6), R50.1
unnamed: IC32.13 (B5), R49.1
unnamed: IC32.14 (B4), R48.1
unnamed: IC32.15 (B3), R47.1
unnamed: IC32.16 (B2), R46.1
unnamed: IC32.17 (B1), R45.1
unnamed: IC32.18 (B0), R44.1
unnamed: IC33.4, IC38.5, IC39.2 (Q0)
unnamed: IC33.8, IC39.8 (D3)
unnamed: IC33.10, IC33.11
unnamed: IC33.13, IC35.11
unnamed: IC34.3, R42.1, TP15.1
unnamed: IC36.6, IC40.9 (~LD)
unnamed: IC36.9, IC37.6, IC42.9
unnamed: IC37.8, IC42.1
unnamed: IC38.3, IC39.18 (D7)
unnamed: IC38.6, IC39.7 (D2)
unnamed: IC38.9, IC39.6 (Q2)

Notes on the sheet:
High: 60Hz Low: 50Hz
High: SUB Low: MAIN

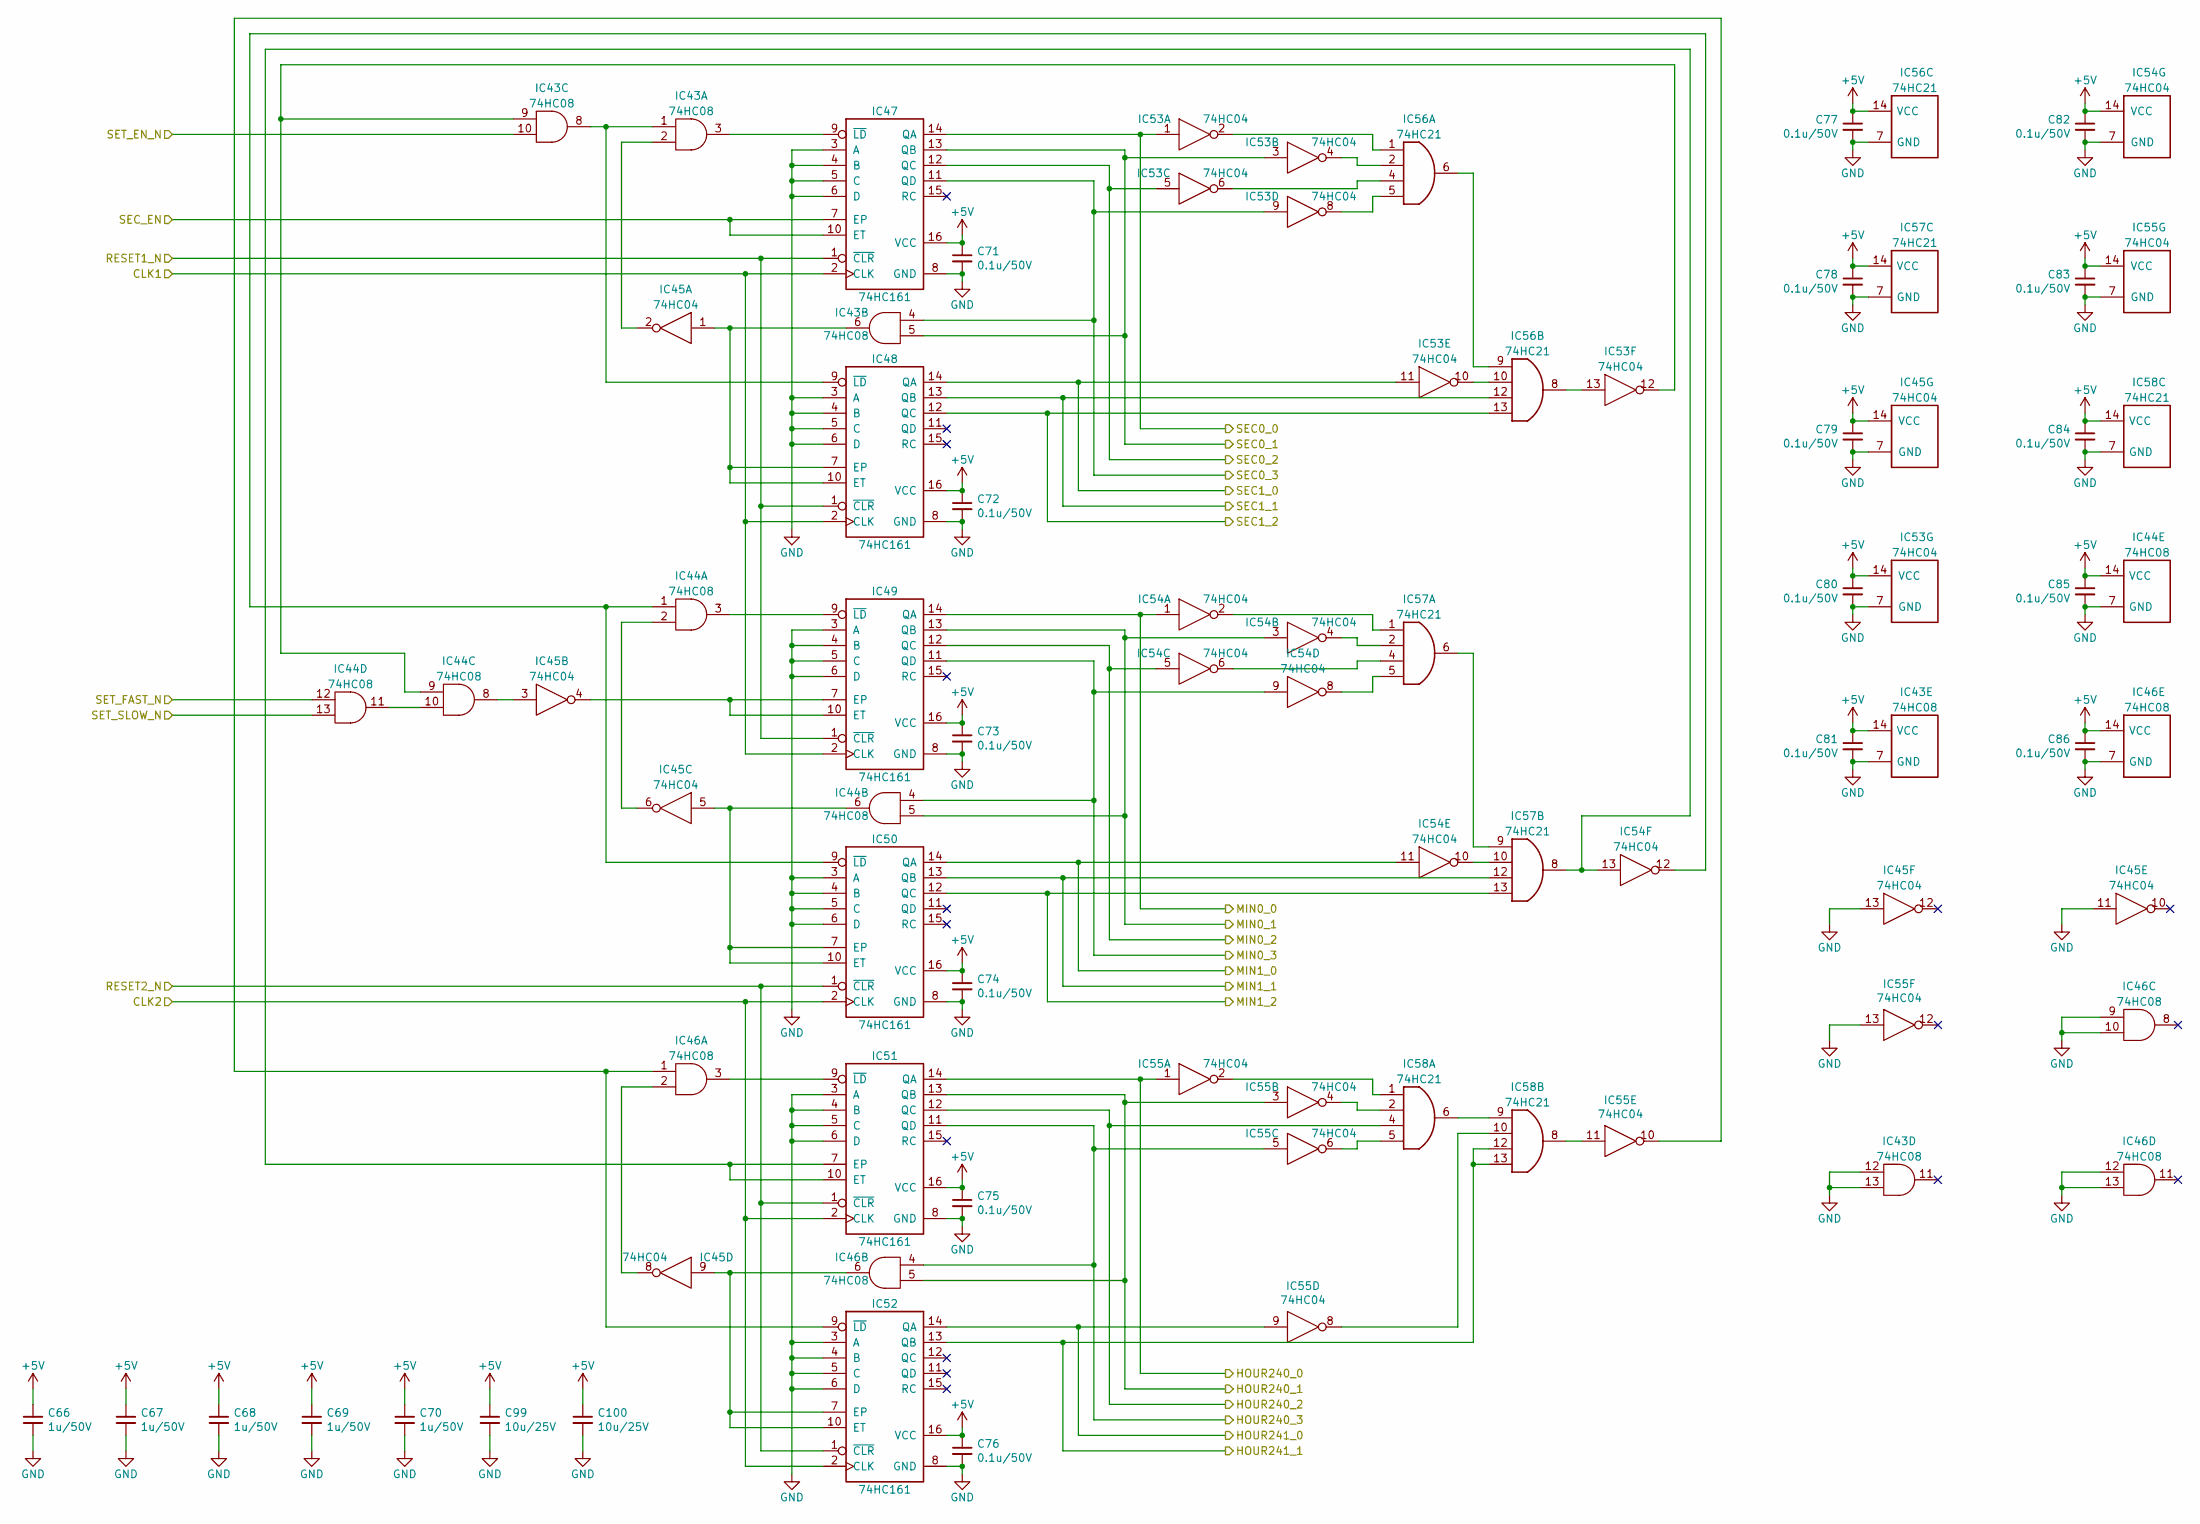
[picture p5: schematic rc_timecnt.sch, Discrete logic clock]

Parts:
C66, C67, C68, C69, C70: 1u/50V; C_Disc_P2.50mm
C71, C72, C73, C74, C75, C76, C77, C78, C79, C80, C81, C82, C83, C84, C85, C86: 0.1u/50V; C_Disc_P2.50mm
C99, C100: 10u/25V; C_Disc_P5.00mm
IC43, IC44, IC46: 74HC08; DIP-14_W7.62mm_Socket_LongPads
IC45, IC53, IC54, IC55: 74HC04; DIP-14_W7.62mm_Socket_LongPads
IC47, IC48, IC49, IC50, IC51, IC52: 74HC161; DIP-16_W7.62mm_Socket_LongPads
IC56, IC57, IC58: 74HC21; DIP-14_W7.62mm_Socket_LongPads

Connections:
+5V: C66.1, C67.1, C68.1, C69.1, C70.1, C71.1, C72.1, C73.1, C74.1, C75.1, C76.1, C77.1, C78.1, C79.1, C80.1, C81.1, C82.1, C83.1, C84.1, C85.1, C86.1, C99.1, C100.1, IC43.14 (VCC), IC44.14 (VCC), IC45.14 (VCC), IC46.14 (VCC), IC47.16 (VCC), IC48.16 (VCC), IC49.16 (VCC), IC50.16 (VCC), IC51.16 (VCC), IC52.16 (VCC), IC53.14 (VCC), IC54.14 (VCC), IC55.14 (VCC), IC56.14 (VCC), IC57.14 (VCC), IC58.14 (VCC); also elsewhere on the board
/Divider block/SEC_EN: IC47.7 (EP), IC47.10 (ET); also elsewhere on the board
/Divider block/SET_FAST_N: IC44.12; also elsewhere on the board
/Divider block/SET_SLOW_N: IC44.13; also elsewhere on the board
/Driver block/HOUR240_0: IC51.14 (QA), IC55.1; also elsewhere on the board
/Driver block/HOUR240_1: IC46.5, IC51.13 (QB), IC55.3; also elsewhere on the board
/Driver block/HOUR240_2: IC51.12 (QC), IC58.4; also elsewhere on the board
/Driver block/HOUR240_3: IC46.4, IC51.11 (QD), IC55.5; also elsewhere on the board
/Driver block/HOUR241_0: IC52.14 (QA), IC55.9; also elsewhere on the board
/Driver block/HOUR241_1: IC52.13 (QB), IC58.12, IC58.13; also elsewhere on the board
/Driver block/MIN0_0: IC49.14 (QA), IC54.1; also elsewhere on the board
/Driver block/MIN0_1: IC44.5, IC49.13 (QB), IC54.3; also elsewhere on the board
/Driver block/MIN0_2: IC49.12 (QC), IC54.5; also elsewhere on the board
/Driver block/MIN0_3: IC44.4, IC49.11 (QD), IC54.9; also elsewhere on the board
/Driver block/MIN1_0: IC50.14 (QA), IC54.11; also elsewhere on the board
/Driver block/MIN1_1: IC50.13 (QB), IC57.12; also elsewhere on the board
/Driver block/MIN1_2: IC50.12 (QC), IC57.13; also elsewhere on the board
/Driver block/SEC0_0: IC47.14 (QA), IC53.1; also elsewhere on the board
/Driver block/SEC0_1: IC43.5, IC47.13 (QB), IC53.3; also elsewhere on the board
/Driver block/SEC0_2: IC47.12 (QC), IC53.5; also elsewhere on the board
/Driver block/SEC0_3: IC43.4, IC47.11 (QD), IC53.9; also elsewhere on the board
/Driver block/SEC1_0: IC48.14 (QA), IC53.11; also elsewhere on the board
/Driver block/SEC1_1: IC48.13 (QB), IC56.12; also elsewhere on the board
/Driver block/SEC1_2: IC48.12 (QC), IC56.13; also elsewhere on the board
/Time count block/CLK1: IC47.2 (CLK), IC48.2 (CLK), IC49.2 (CLK); also elsewhere on the board
/Time count block/CLK2: IC50.2 (CLK), IC51.2 (CLK), IC52.2 (CLK); also elsewhere on the board
/Time count block/RESET1_N: IC47.1 (~CLR), IC48.1 (~CLR), IC49.1 (~CLR); also elsewhere on the board
/Time count block/RESET2_N: IC50.1 (~CLR), IC51.1 (~CLR), IC52.1 (~CLR); also elsewhere on the board
/Time count block/SET_EN_N: IC43.10; also elsewhere on the board
GND: C66.2, C67.2, C68.2, C69.2, C70.2, C71.2, C72.2, C73.2, C74.2, C75.2, C76.2, C77.2, C78.2, C79.2, C80.2, C81.2, C82.2, C83.2, C84.2, C85.2, C86.2, C99.2, C100.2, IC43.7 (GND), IC43.12, IC43.13, IC44.7 (GND), IC45.7 (GND), IC45.11, IC45.13, IC46.7 (GND), IC46.9, IC46.10, IC46.12, IC46.13, IC47.3 (A), IC47.4 (B), IC47.5 (C), IC47.6 (D), IC47.8 (GND), IC48.3 (A), IC48.4 (B), IC48.5 (C), IC48.6 (D), IC48.8 (GND), IC49.3 (A), IC49.4 (B), IC49.5 (C), IC49.6 (D), IC49.8 (GND), IC50.3 (A), IC50.4 (B), IC50.5 (C), IC50.6 (D), IC50.8 (GND), IC51.3 (A), IC51.4 (B), IC51.5 (C), IC51.6 (D), IC51.8 (GND), IC52.3 (A), IC52.4 (B), IC52.5 (C), IC52.6 (D), IC52.8 (GND), IC53.7 (GND), IC54.7 (GND), IC55.7 (GND), IC55.13, IC56.7 (GND), IC57.7 (GND), IC58.7 (GND); also elsewhere on the board
unnamed: IC43.1, IC43.8, IC48.9 (~LD)
unnamed: IC43.2, IC45.2
unnamed: IC43.3, IC47.9 (~LD)
unnamed: IC43.6, IC45.1, IC48.7 (EP), IC48.10 (ET)
unnamed: IC43.9, IC44.9, IC53.12
unnamed: IC44.1, IC50.9 (~LD), IC54.12
unnamed: IC44.2, IC45.6
unnamed: IC44.3, IC49.9 (~LD)
unnamed: IC44.6, IC45.5, IC50.7 (EP), IC50.10 (ET)
unnamed: IC44.8, IC45.3
unnamed: IC44.10, IC44.11
unnamed: IC45.4, IC49.7 (EP), IC49.10 (ET)
unnamed: IC45.8, IC46.2
unnamed: IC45.9, IC46.6, IC52.7 (EP), IC52.10 (ET)
unnamed: IC46.1, IC52.9 (~LD), IC55.10
unnamed: IC46.3, IC51.9 (~LD)
unnamed: IC51.7 (EP), IC51.10 (ET), IC54.13, IC57.8
unnamed: IC53.2, IC56.1
unnamed: IC53.4, IC56.2
unnamed: IC53.6, IC56.4
unnamed: IC53.8, IC56.5
unnamed: IC53.10, IC56.10
unnamed: IC53.13, IC56.8
unnamed: IC54.2, IC57.1
unnamed: IC54.4, IC57.2
unnamed: IC54.6, IC57.4
unnamed: IC54.8, IC57.5
unnamed: IC54.10, IC57.10
unnamed: IC55.2, IC58.1
unnamed: IC55.4, IC58.2
unnamed: IC55.6, IC58.5
unnamed: IC55.8, IC58.10
unnamed: IC55.11, IC58.8
unnamed: IC56.6, IC56.9
unnamed: IC57.6, IC57.9
unnamed: IC58.6, IC58.9

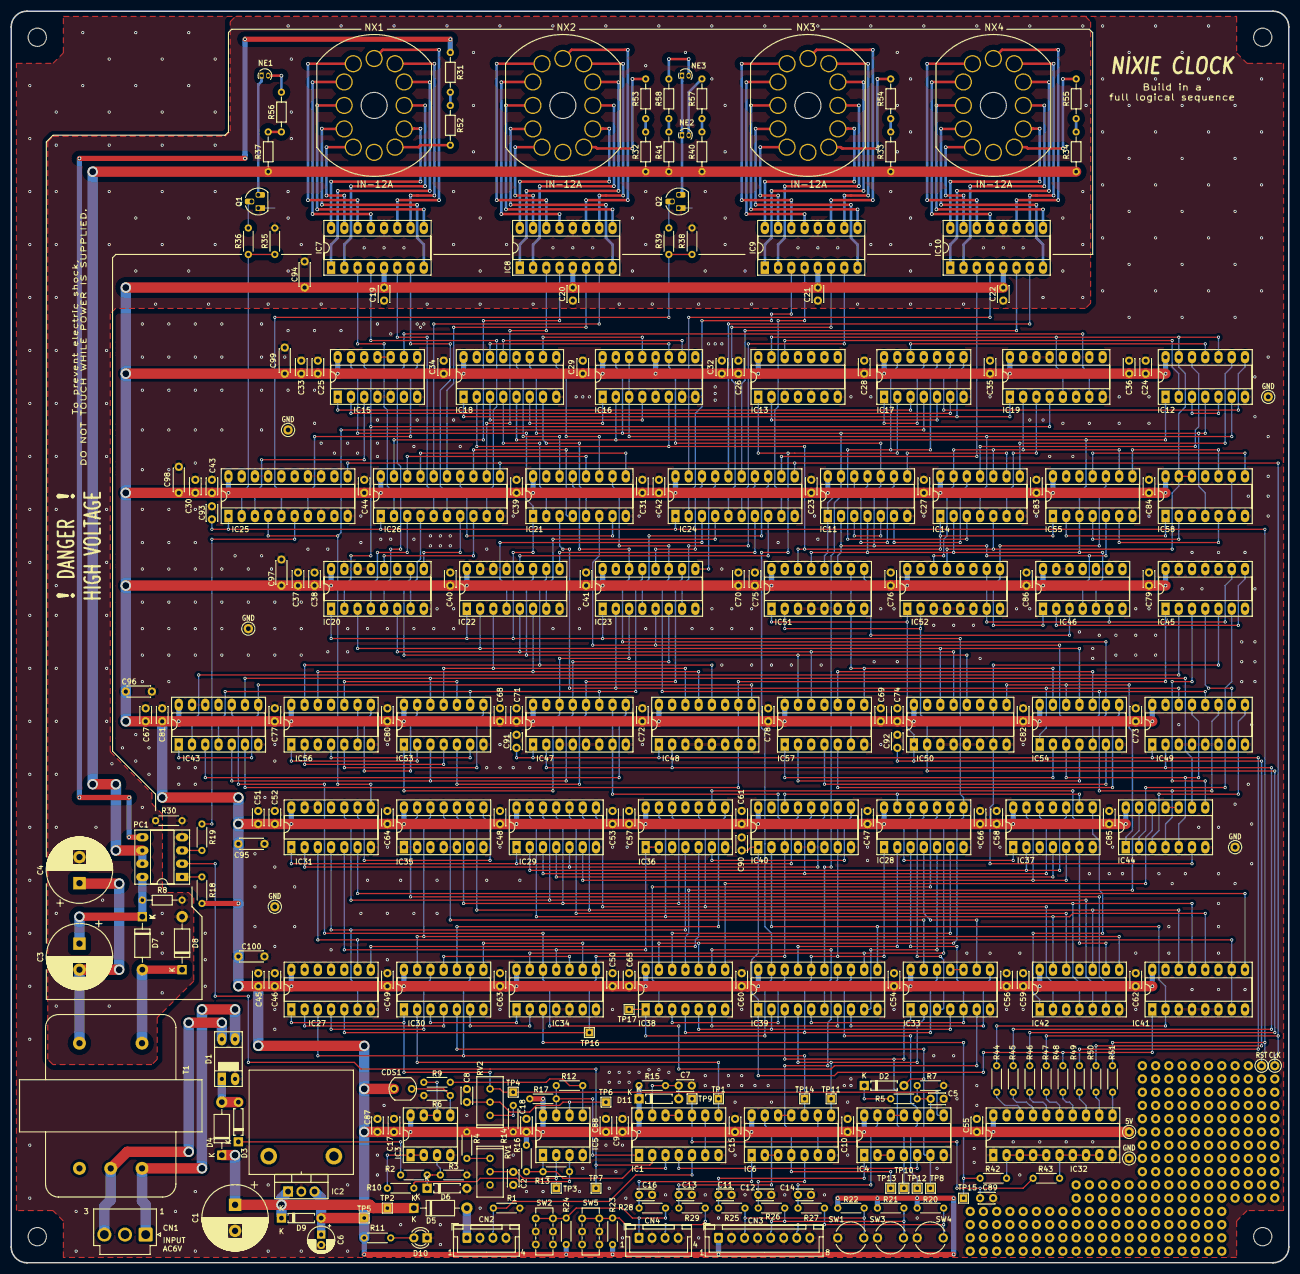
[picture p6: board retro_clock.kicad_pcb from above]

Board: 2 copper layers, 245.0 x 240.0 mm, 276 parts (0 on the bottom side), 316 nets.

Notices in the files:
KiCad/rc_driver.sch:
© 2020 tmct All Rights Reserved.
